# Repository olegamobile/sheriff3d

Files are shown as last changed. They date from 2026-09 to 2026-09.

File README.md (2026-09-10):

# ⛵ Jouët Sheriff 600 — Высокоточная 3D модель для печати

Параметрическая 3D-модель классической французской парусной яхты **Jouët Sheriff 600** (конструктор — **Philippe Harlé**, верфь — **Yachting France**, 1969–1976 гг.), созданная по оригинальным чертежам теоретического чертежа (Lines Plan) из журнала *Bateaux* (октябрь 1969 и июль 1973), официальной документации верфи и архивным фотографиям.

Модель полностью твердотельная (100% Watertight 2-manifold) и оптимизирована для FDM 3D-принтера **Flashforge Adventurer 3** (область печати 150 × 150 × 150 мм) в масштабе **1:45**, а также экспортирована в масштабе **1:1**.

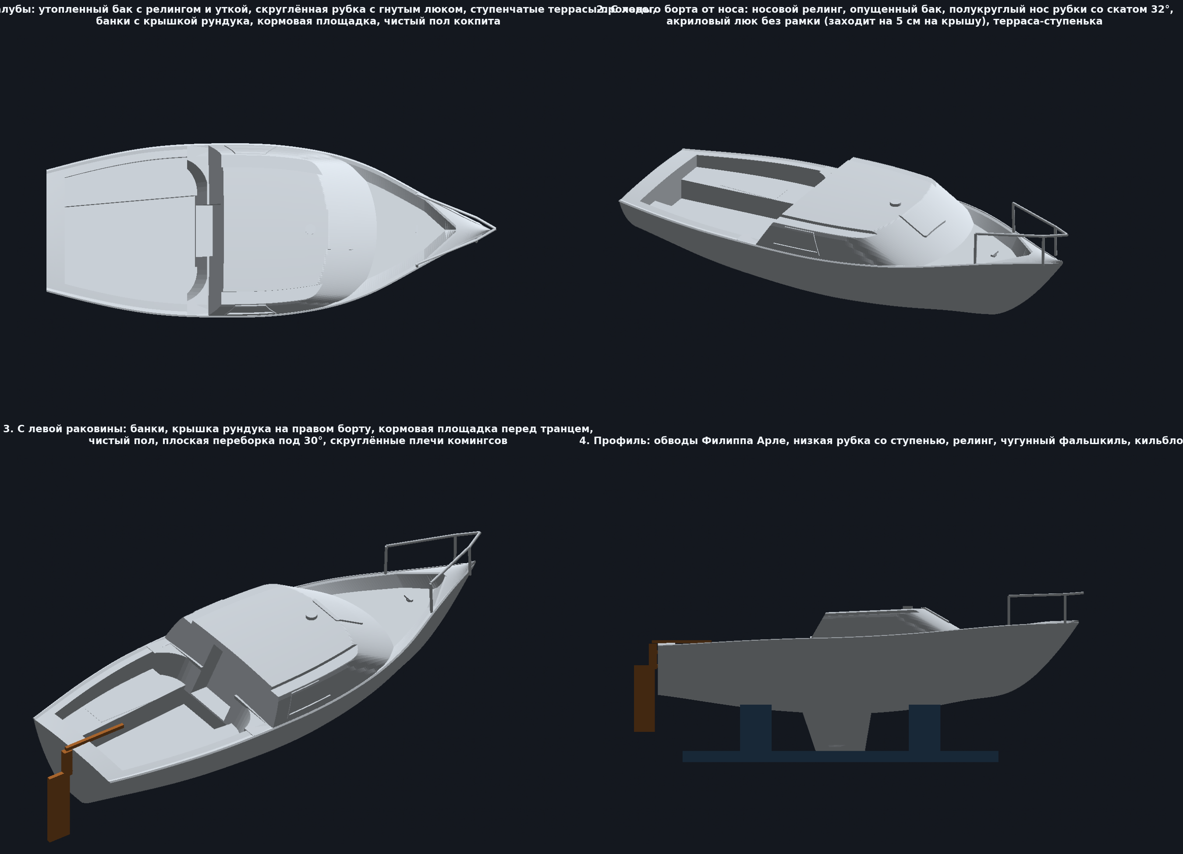
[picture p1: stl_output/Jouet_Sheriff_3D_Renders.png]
Jouet Sheriff 600 3D Renders


---

## 📐 Характеристики прототипа (Jouët Sheriff 600)

- **Длина наибольшая (LOA):** 6.00 м (6000 мм)
- **Длина по КВЛ (LWL):** 5.00 м (5000 мм)
- **Ширина наибольшая (Bmax):** 2.31 м (2310 мм)
- **Осадка (Draft):** 0.85 м (чугунный фальшкиль)
- **Высота надводного борта:** нос — 980 мм, мидель — 760 мм, транец — 650 мм
- **Водоизмещение:** ~850 кг (балласт 300 кг)
- **Материал оригинала:** Стеклопластик (GRP)

---

## 🧩 Особенности геометрии версии V4 (палуба по фотографиям реальной лодки)

Подводная часть, обводы, транец, фальшкиль и стыковочные пазы киля не менялись с V3. Палуба, рубка и кокпит построены заново по фотографиям из `real_photos/`:

1. **Утопленный бак.** Узкий планширь (50 мм) остаётся на уровне борта и чуть наклонён внутрь, дальше скос 150 мм вниз к опущенной палубе: у рубки она ниже на 70 мм, к носу — на 160 мм; к штевню углубление сходится клином. Посередине бака — маленькая **швартовая утка поперёк лодки**.
2. **Рубка во всю ширину:** боковые стенки — плоские, поднимаются прямо от кромки борта (привального бруса), повторяя его обводы, наклонены внутрь на 20°; крыша почти плоская, кормовые углы острые. Вдоль обоих краёв крыши от кормовой кромки до самого её конца (канавка выбегает на скат и заканчивается ровно на дуге перегиба) идут **проходы-канавки** (220 мм, глубина 20 мм); ободок снаружи от канавки **трапециевидный**: внешняя грань — продолжение стенки, плоский верх 30 мм, скос 45° в канавку. По одному **трапециевидному окну** на борт (700/410 × 250 мм) целиком на стенке: верх и низ параллельны линии края крыши (45 мм от неё), наклонные рёбра параллельны кормовой переборке; приподнятая алюминиевая рамка и утопленное тонированное стекло.
3. **Скруглённый нос рубки:** плоская крыша впереди заканчивается полуэллипсом (400 мм вперёд по ДП), и от этой дуги передняя грань падает вперёд под 32° — поэтому и перегиб на крыше, и линия подножия на баке являются дугами, а углы к боковым стенкам плавно сглажены. На скате вверху — **люк из тонированного акрила** (плоская пластина без рамки), его задний край на ~50 мм перегибается через кромку на крышу. Мачта стоит на крыше чуть позади перегиба.
4. **Кормовая переборка** — одна плоскость, наклонённая вперёд на 30° (параллельно заднему ребру окна), спускается на 50 мм ниже уровня банок до порожка (Z 450, банки Z 500) и поднимается до крыши. Ниже уровня борта по бортам от неё рубка выступает назад вдоль комингсов «крыльями» (R 450), которые заканчиваются **вогнутыми четвертями окружности** (центр дуги в кокпите), касательными к комингсу и к переборке: каждая банка упирается в полукруглую стенку. Верх крыльев — на уровне планширя, заподлицо с ним. **Выше уровня борта** переборка — одна плоскость во всю ширину с острыми углами. В переборке **большой вход в рубку** — проём 700 мм от порожка почти до крыши, выполненный карманом глубиной 200 мм.
5. **Открытый кокпит:** плоская полоса планширя по борту (150 мм), упирающаяся в крылья рубки, ниже — банки, между ними углублённый пол; банки и пол идут до самого транца (кормовой банки нет, рундука нет). Банки заканчиваются полукруглыми карманами у крыльев рубки.
6. **Доска-упор для ног, стойки и балка оттяжки гика** в полу кокпита: доска 55 мм шириной лежит плашмя вдоль почти всего пола на двух стойках у его концов, поперечная балка между банками проходит над ней. Сечения увеличены до ~1,3 мм в масштабе ради печатаемости.
7. **Транец, навесной руль и румпель:** транец сплошной, перо руля навешивается снаружи, румпель проходит над транцем.
8. **Все плоские поверхности — точные плоскости:** рубка и кокпит собраны булевыми операциями (`manifold3d`), а не деформацией сетки корпуса, поэтому скат, крыша, банки, пол и переборка не имеют волн и ступенек.

---

## 📂 Файлы в репозитории (`stl_output/`)

### Масштаб 1:45 (Для Flashforge Adventurer 3, 150×150×150 мм)

| Файл | Назначение | Размеры (X × Y × Z, мм) | Особенности печати |
| :--- | :--- | :--- | :--- |
| **`Jouet_Sheriff_Waterline_1to45.stl`** | Ватерлинейная модель (только надводная часть: борта, палуба, рубка, кокпит) | 133.3 × 52.3 × 26.8 | **Печать БЕЗ поддержек**. Ложится плоским дном по КВЛ прямо на стол. ~22 г PLA, ~3 часа. |
| **`Jouet_Sheriff_Split_Keel_1to45.stl`** | Нижняя половина (днище и фальшкиль с балластом) | 111.9 × 29.2 × 19.0 | **Печать БЕЗ поддержек**. Верх плоский (Z=0), класть срезом на стол. Внутри 2 паза под штифты. ~4.5 г PLA, ~45 мин. |
| **`Jouet_Sheriff_Split_Deck_1to45.stl`** | Верхняя половина (палуба, рубка, кокпит под склейку с килем) | 133.3 × 52.3 × 26.8 | **Печать БЕЗ поддержек**. Внизу 2 паза под штифты. ~22 г PLA, ~3 часа. |
| **`Jouet_Sheriff_Full_1to45.stl`** | Монолитная модель (корпус с килем целиком) | 133.3 × 52.3 × 45.8 | Требуются древовидные поддержки под скулы корпуса. |
| **`Jouet_Sheriff_Rudder_1to45.stl`** | Навесной руль с румпелем и петлями транца | 24.6 × 1.7 × 29.1 | Печатать плашмя. ~0.3 г PLA, ~15 мин. |
| **`Jouet_Sheriff_Display_Cradle_1to45.stl`** | Настольный кильблок-подставка под обводы днища | 100.0 × 48.9 × 18.3 | **Печать БЕЗ поддержек**. |
| **`Jouet_Sheriff_Rigging_1to45.stl`** | Рангоут (мачта 151 мм, гик, краспицы) | 61.0 × 21.1 × 151.1 | Печать по диагонали стола Adventurer 3 (диагональ 212 мм). |
| **`Jouet_Sheriff_Assembly_Preview.obj`** | 3D-сцена сборки (лодка + кильблок + руль) | — | Для открытия в 3D-просмотрщике или слайсере. |

### Полноразмерные модели (Масштаб 1:1, LOA = 6000 мм)
- **`Jouet_Sheriff_Full_1to1.stl`** (6000 × 2354 × 2060 мм)
- **`Jouet_Sheriff_Waterline_1to1.stl`** (6000 × 2354 × 1205 мм)

---

## 🎨 Интеграция с Blender (Blender MCP & `.blend`)

В репозиторий добавлен готовый проект для Blender:
- **`Jouet_Sheriff_600.blend`** — Сцена Blender 5.2 со структурированными коллекциями:
  - `Jouet_Sheriff_1to45` (разбитая на детали модель: палуба, киль, руль, рангоут, кильблок).
  - Настроенные PBR-материалы (гелькоут корпуса, тиковые банки, тонированный акрил, чугунный киль, алюминиевый рангоут).
  - Студийный свет (Key, Fill, Rim) и настроенная камера.
- **`build_blender_project.py`** — Автоматический скрипт сборки сцены в Blender.
- **Blender MCP:** настроен аддон `blender_mcp` и сервер для прямого взаимодействия AI-агентов с 3D-вьюпортом Blender.

---

## 🖨️ Рекомендации по печати на Flashforge Adventurer 3

1. **Слайсер:** FlashPrint (или Cura / OrcaSlicer с профилем Adventurer 3).
2. **Материал:** PLA (белый для палубы/корпуса, коричневый/серый для руля и кильблока).
3. **Высота слоя:** `0.18 мм` (стандарт) или `0.12 мм` (высокая детализация).
4. **Стенки (Shells):** 2 периметра (0.8 мм).
5. **Заполнение (Infill):** 15% (Gyroid или Hexagon).
6. **Сборка разборной модели (`Split_Deck` + `Split_Keel`):**
   - Обе детали имеют ответные отверстия диаметром ~2.4 мм на плоскости ватерлинии: в киле глубиной 4 мм, в палубе — 2.9 мм (над кормовым отверстием лежит пол кокпита).
   - Отрежьте два кусочка обычного прутка PLA 1.75 мм длиной по 6–6.5 мм.
   - Вставьте их в отверстия в качестве центровочных штифтов и соедините половинки на каплю цианакрилатного клея (суперклея).

---

## 🛠️ Структура скриптов и генерация

- **`generate_sheriff_models.py`** — Главный генератор всех STL и OBJ моделей.
  - Корпус: сплайны по 13 шпангоутам, непрерывные замкнутые шпангоутные кольца (Ring Topology) с плоской палубой.
  - Рубка, кокпит, окна, люк, утка, рундук и стойки — отдельные тела, объединённые/вырезанные через `manifold3d`. Все размеры палубы вынесены в блок параметров в начале файла.
- **`render_v3_clean.py`** — Рендер предпросмотра (4 ракурса): собственный ортографический z-buffer-растеризатор с диффузным освещением. Не используйте `Poly3DCollection` из mplot3d — он сортирует полигоны по центрам и на длинных треугольниках после CSG рисует ложные «рваные» полосы.
- **`real_photos/`** — Фотографии конкретной лодки, главный ориентир для палубы.
- **`chez_downloads/`** и **`extracted_pdf_assets/`** — Исходные материалы, PDF выпусков журнала *Bateaux* и извлеченные сканы чертежей.

### Установка и запуск:
```bash
python3 -m venv .venv
.venv/bin/pip install numpy scipy trimesh manifold3d matplotlib networkx rtree shapely pillow
.venv/bin/python generate_sheriff_models.py
.venv/bin/python render_v3_clean.py
```

---

## 📌 Инструкции для разработчиков и AI-агентов

Если вы дорабатываете проект с помощью AI-агента (Cursor, Claude, Copilot, Antigravity), обязательно ознакомьтесь с файлом [AGENTS.md](AGENTS.md) — там описана математическая модель, правила сохранения водонепроницаемости сетки и план модификации палубной части по индивидуальным замерам.

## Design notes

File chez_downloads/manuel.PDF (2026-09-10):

# Manuel de l'utilisateur

CARACTERISTIQUES PRINCIPALES

- Longueur maximum - avec balcon | 6 m 22
- Longueur maximum - sans balcon | 6 m 08
- Largeur au maître bau | 2 m 36
- Longueur flottaison | 4 m 70
- Hauteur totale (sans capote) | 2 m 06
- Tirant d'eau | 0 m 92
- Déplacement à vide (départ usine, sans suppléments) | 825 Kg
- Volume d'insubmersibilité (mousse polyuréthane) | 1 m3600
- Surface grand'voile | 10m260
- Surface foc n° 1 | 4m295
- Surface génois | 9m285
- Surface tourmentin | 2m250
- Surface spinnaker | 25 m2
- Jauge brute | 2 Tx 98
- Poid du lest | 225 Kg

## Shemas non commentés :

Plan de voilure

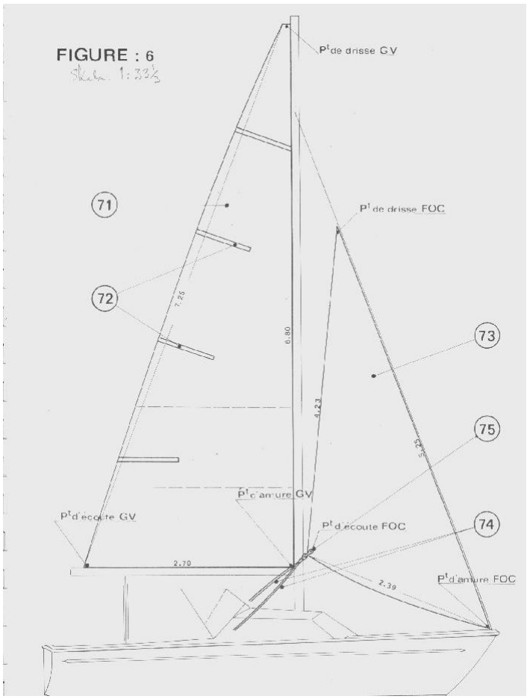
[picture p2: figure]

Détail voilure

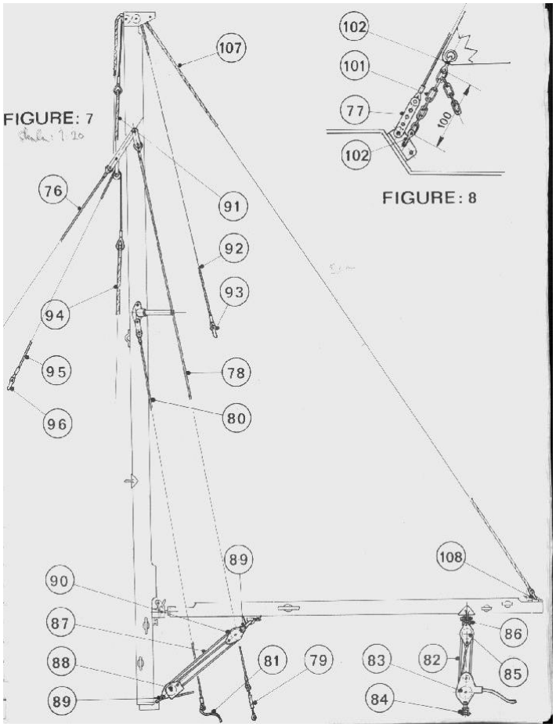
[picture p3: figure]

Pied de mât

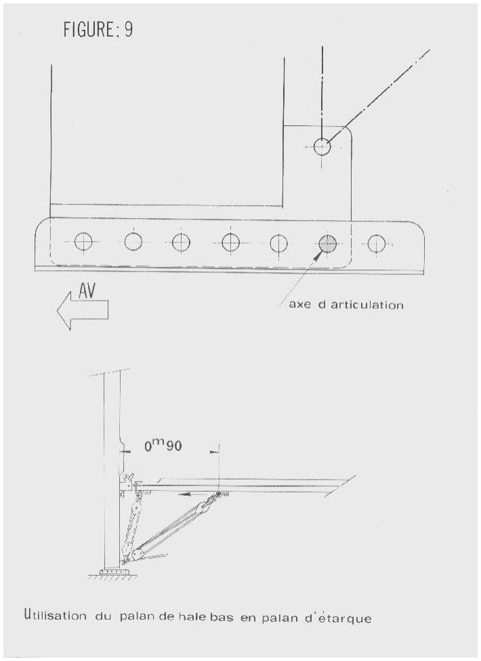
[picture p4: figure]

Béquillage

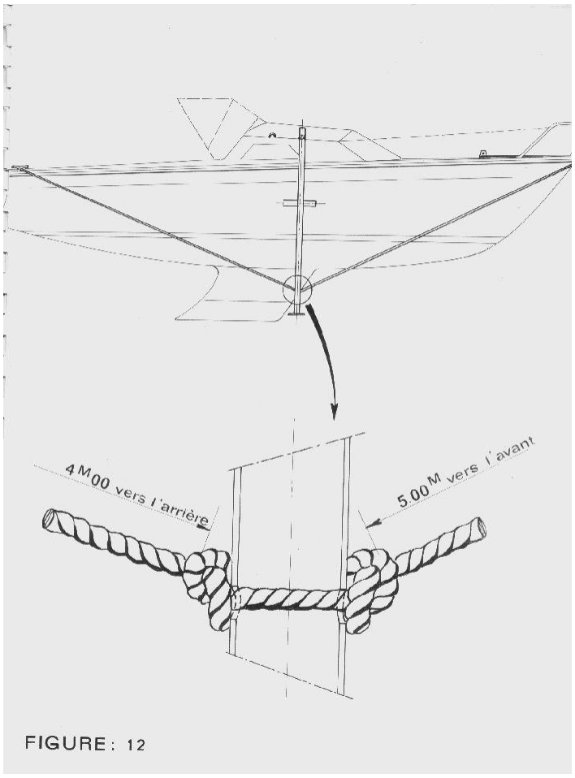
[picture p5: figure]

Capote

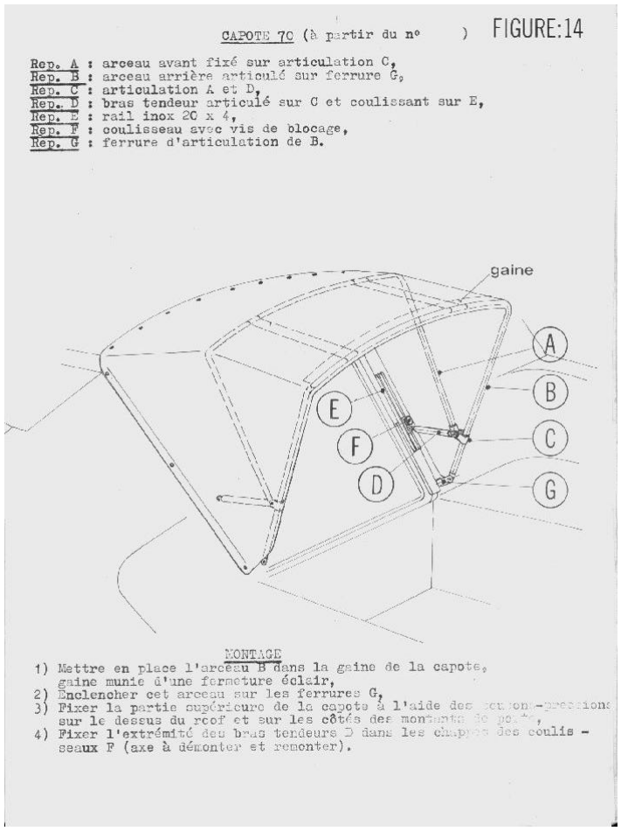
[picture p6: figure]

WC Marin

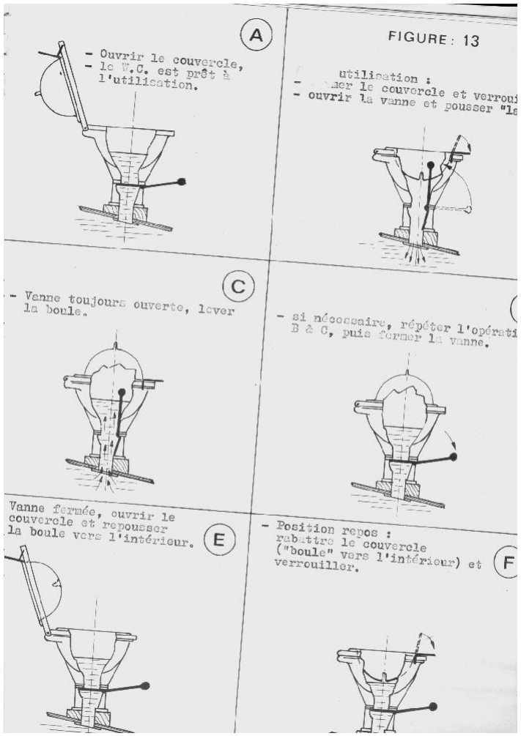
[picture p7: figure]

ACCASTILLAGE :

Pont (figure 1) :

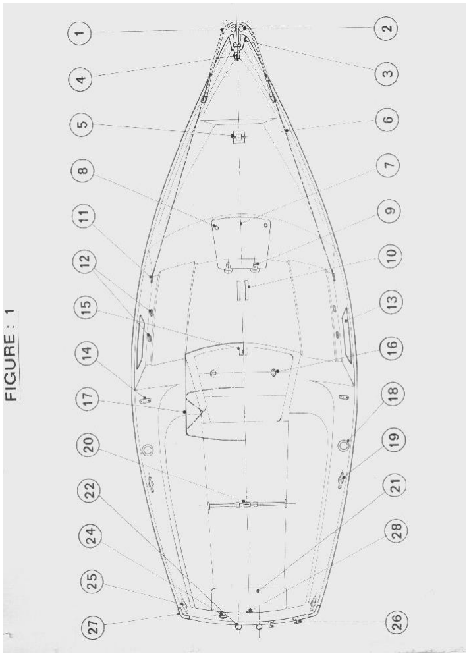
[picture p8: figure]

1 | 1 balcon avant en tube inox,
2 | 2 feux de route rouge et vert, (version luxe)
3 | 1 davier d'étrave,
4 | 1 ferrure d'étai,
5 | 1 bitte aérateur,
6 | 1 filière câble gaine plastique (version luxe)

7 | 1 panneau avant ouvrant en plexiglas,
8 | 2 poignées de fermeture du panneau,
9 | 2 charnières de panneau,
10 | 2 cornières de pied de mât,
11 | 2 ferrures d'accrochage de filière, (version luxe)
12 | 4 cadènes de haubans et bas-haubans,
13 | 2 hublots avec entourage alu,
14 | 2 filoirs plastique,
15 | 1 serrure de porte d'entrée de cabine, avec 2 clefs,
16 | 2 charnières de porte d'entrée de cabine,
17 | 1 capote rabattable,
18 | 2 winches nylon,
19 | 2 taquets nylon,
20 | 1 barre d'écoute avec coulisseau et butées,
21 | 1 banc arrière amovible,
22 | 2 balles de vidange,
24 | 1 ensemble douille et dame de nage,
25 | 2 taquets arrière nylon,
26 | 2 rails pour chaise moteur H.B. (GOIOT -Réf. 900)
27 | 2 embouts de défense arrière,
28 | 1 plaque de constructeur,

2 - AMENAGEMENT INTERIEUR

(figure 2) :

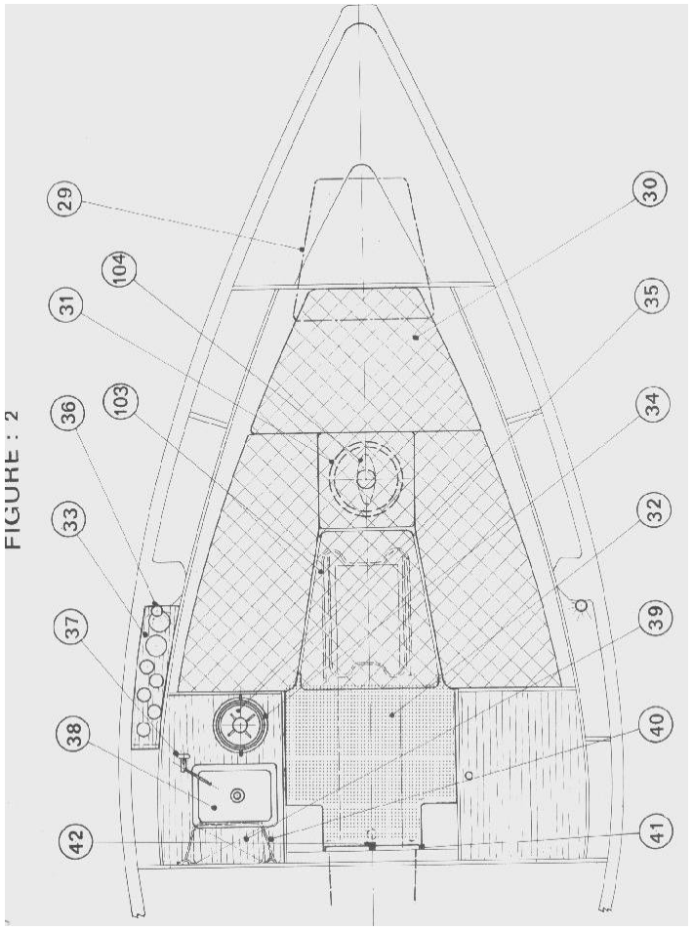
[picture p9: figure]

29 | 1 panneau amovible formant allonge de couchette rangement sous pontage,
103 | 1 jeu de pieds repliables pour utilisation du panneau en table repas (version luxe)
30 | 1 jeu de 5 coussins,

31 | 1 WC plastique, (version luxe)
32 | 1 moquette,
33 | 1 équipet à bouteilles et verres,
34 | 1 cardan à réchaud (version luxe)
35 | 1 bouteille 40 heures avec brûleur, (version luxe)
36 | 2 feux blancs d'intérieur, (version luxe)
37 | 1 pompe Whale à main, (version luxe)
38 | 1 évier plastique avec vidange, (version luxe)
39 | 1 jerrican de 10 litres, (version luxe)
40 | 1 sandow avec 2 crampons, (version luxe)
41 | 1 trappe de glacière,
42 | 1 fermeture de glacière,
104 | 1 pièce alu de profilage sortie WC (version luxe)

3 - GOUVERNAIL

(figure 3, 4 et 5) :

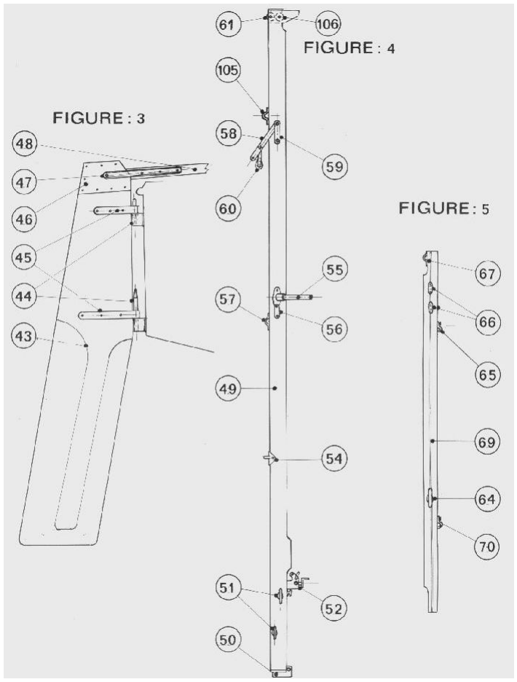
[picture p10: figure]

43 | 1 safran en acajou verni,
44 | 2 aiguillots sur tableau,
45 | 2 fémelots sur gouvernail,
46 | 2 plaques d'usure,
47 | 2 lattes d'articulation de

barre,
48 1 barre en frêne.

B - MATURE, VOILURE, GREEMENT :

1 - MAT (figure 4) :

49 | 1 profilé de mât métallique anodisé,
50 | 1 pied de mât, avec axe et écrou,
51 | 4 taquets de drisses,
52 | 1 articulation de bôme,
54 | 1 œil de tangon,
55 | 2 barres de flèche,
56 | 2 lattes de bas-haubans,

## Comment gréer votre " SHERIFF "

A - Dressage du mat :

S'assurer préalablement, à l'aide de votre liste (P. 4-5-6) que le gréement est complet. Tout doit être clair sur le mât ; Vérifier que toutes les pièces du mât, réas, ferrures, poulies, drisses, manilles, sont bien fixées. Mâter légèrement les écrous. Fixer les ridoirs, lattes et aiguillettes
(1) sur les galhaubans, étai, bas-haubans. Les détendre au maximum en s'assurant toutefois, pour les ridoirs, qu'il reste suffisamment de filets engagés dans la cage. L'étai doit être fixé provisoirement au dernier trou sur les lattes (77) figure 8. Fixer les bas-haubans (80) sur les cadènes avant du roof en utilisant les aiguillettes. Ramener tous les autres filins le long du mât et les y maintenir en les ceinturant avec un sandow, l'étai bien dégagé sur la face avant du mât. Dresser le mât sur son embase, le sabot de pied de mât venant entre les deux cornières fixées sur le roof, caler avec le pied. Une fois vertical, un seul homme suffit à le tenir en poussant vers l'avant pendant que l'on fixe d'étai. 1) Fixer l'étai avant sur le premier trou de la ferrure d'étrave (figure 8) ; 2) Fixer les deux ridoirs de galhaubans sur les cadènes arrière ; à ce moment, le mât tient seul ; 3) Le gréement étant détendu, fixer le sabot de pied de mât, passer l'axe dans le deuxième trou en partant de l'arrière sur les cornières (figure 9) ; 4) Fixer les aiguillettes des bas-haubans sur les cadènes avant du roof. (1) Aiguillettes : Bouts de nylon de faible diamètre qui, passés plusieurs fois dans l'œil des bas-haubans et dans la cadène correspondante, remplacent les ridoirs. L'avantage de ce système, en plus de l'économie de poids et de prix, est qu'on obtient quasi automatiquement la tension requise pour un bon réglage.

B- TENSION DES HAUBANS :

A L'arrêt, il ne faut pas que le mât penche sur bâbord ou tribord. S'assurer, avant matage, que les haubans bâbord et tribord ont la même longueur ; Ceci est valable pour les bas-haubans. Tendre d'abord l'étai avant (2ème ou 3ème trou). Tendre ensuite les galhaubans pour terminer pas les bas-haubans (aiguillettes) ; Les bas-haubans doivent être sensiblement moins tendus que les galhaubans. L'étai avant doit être le plus tendu. Un coup d'œil sur l'engoujure du mât vers le haut vous confirmera que le mât n'est pas infléchi sur bâbord ou sur tribord. Il doit avoir une légère quête sur l'arrière. Si le mât est bien en place au repos, encore faut-il qu'il en soit de même quand les voiles sont enverguées. Il y aura lieu de parfaire le réglage sous voiles en mer. Après quelques sorties en mer, surtout par brise fraîche, il faudra reprendre le jeu dû à l'allongement des câbles neufs.

III - REGLAGES

1 - LE FOC : Les filoirs d'écoute ont une position fixe. Par conséquent, pour avoir un point de tir correct, il faut régler le point d'armure sur le foc. En principe, 100 mm de chaîne sont utilisés pour la fixation du point d'armure ; Mais si le foc faseye dans le haut, il faut rehausser cette distance et repérer le maillon utilisé. Procéder de même pour le génois.

2 - LA GRAND'VOILE : Il n'y a aucun réglage à faire, sinon d'essayer de lui donner plus ou moins de creux suivant la force du vent et l'allure. Par vent faible et aux allures portantes, ne pas trop tendre la ralingue sur la bôme et ne pas trop étarquer. Par vent fort et au plus près, tendre fortement la ralingue sur la bôme et étarquer à bloc en tirant la bôme vers le bas.

3- LA PRISE DE RIS (figure 10 & 11) : 1- Se mettre en panne (le foc bordé à contre - la barre à fond sous le vent). 2- Choquer la drisse de grand'voile, 3- Passer la bosse dans l'œil arrière de la bande de ris si elle n'est pas déjà en place, suivant figure 10.

4- Crocher l'œil extrême avant de la bande de ris dans le croc de la ferrure de bôme.

5- Étarquer la voile sur la bôme à l'aide de la bosse de ris. Une fois raidie à fond, tourner la bosse sur le taquet de la bôme.

6- Hisser la voile et étarquer la drisse.

7- Nouer les garcettes. Même principe pour la deuxième bande de ris - en utilisant le réa situé en avant du premier ris.

NOTA Cette méthode permet également de prendre des ris, le bateau étant en route -(du vent de travers au vent arrière, la voile peut être difficile à amener étant plaquée contre les haubans par le vent). Dans ce cas, border la grande écoute un peut plus que la normale pour dégager la voile.

IV UTILISATION DES ACCESSOIRES GREEMENT DE SPI

(figure 15) :

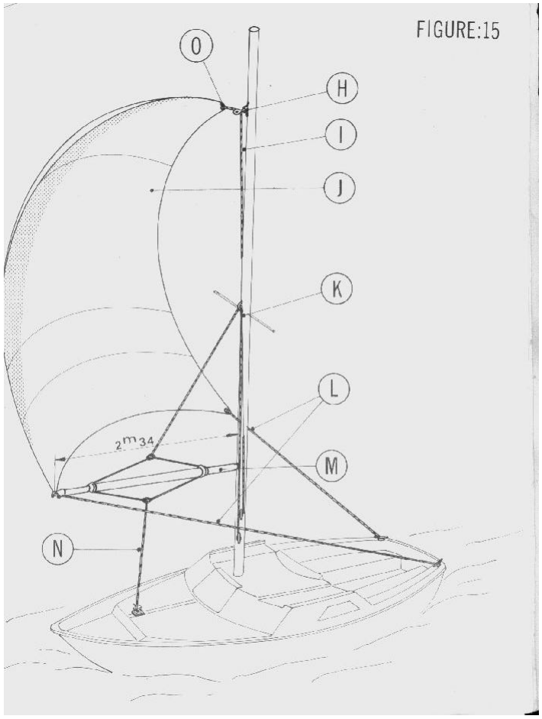
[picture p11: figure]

Rep. O | 1 mousqueton
Rep. I | 1 drisse longueur 12 m 50 - Diamètre 8 polypropylène
Rep. | 1 poulie à axe amovible

H
Rep K | 1 hale-haut polypropylène - Diamètre 8 -Longueur 5 m 50
Rep J | 1 spinnaker,
Rep L | 2 bras ou écoute de spi tergal tressé diamètre 8, longueur 8 m 20 chaque
Rep M | Tangon télescopique (longueur maxi. Jauge 2 m 34)
Rep N | 1 hale-bas polypropylène diamètre 8 -longueur 3 m 00

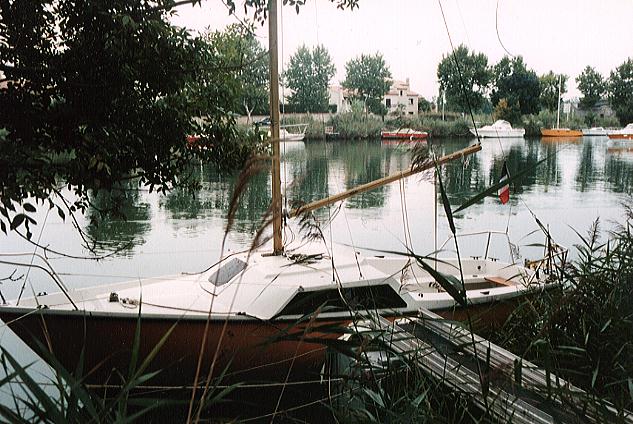
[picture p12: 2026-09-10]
downloaded_assets/assets/photos/horn.jpg

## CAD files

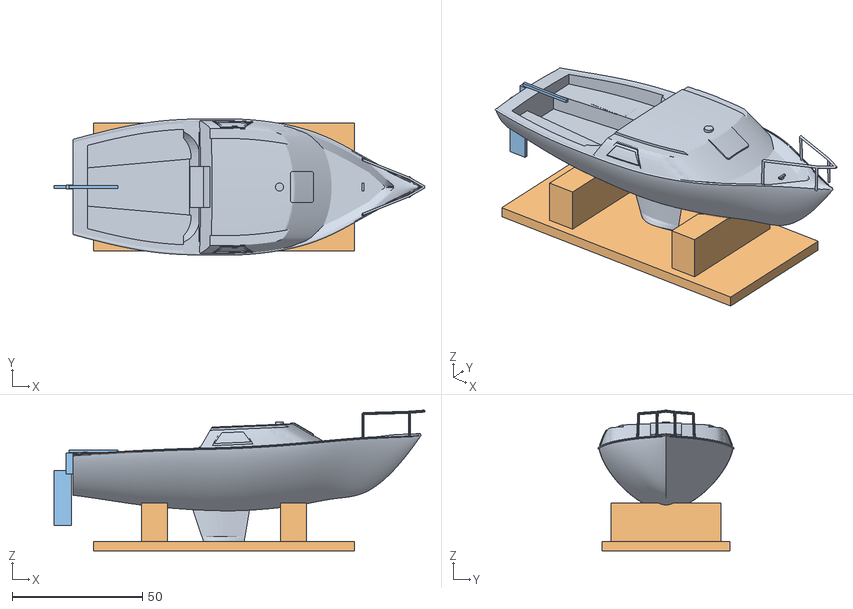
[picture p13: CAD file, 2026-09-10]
stl_output/Jouet_Sheriff_Assembly_Preview.obj
142.2 x 52.3 x 54.0
geometry_0
geometry_1
geometry_2

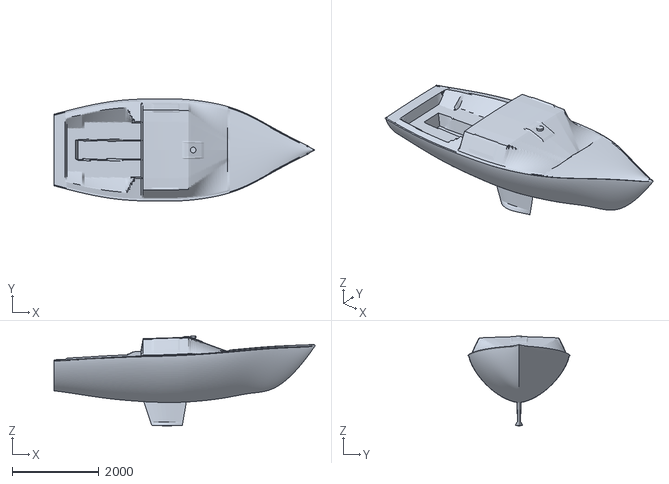
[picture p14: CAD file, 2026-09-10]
test_full_v3.stl
6000.0 x 2354.0 x 2060.8

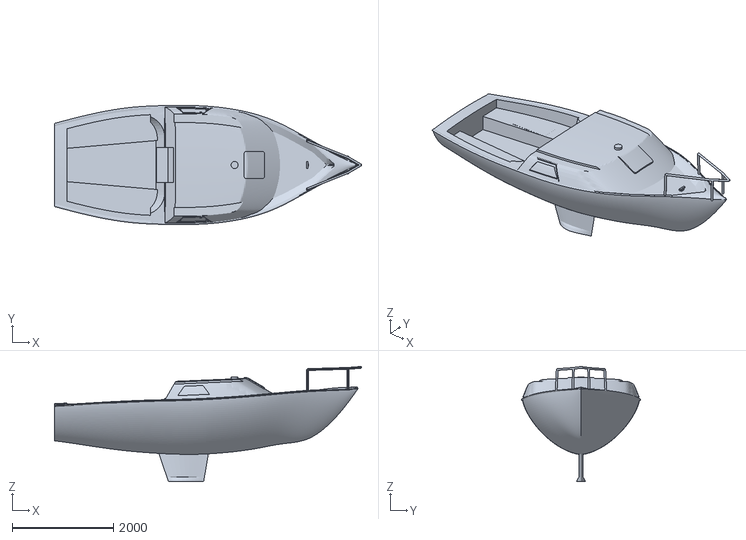
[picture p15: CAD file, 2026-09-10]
stl_output/Jouet_Sheriff_Full_1to1.stl
6069.0 x 2354.0 x 2274.5

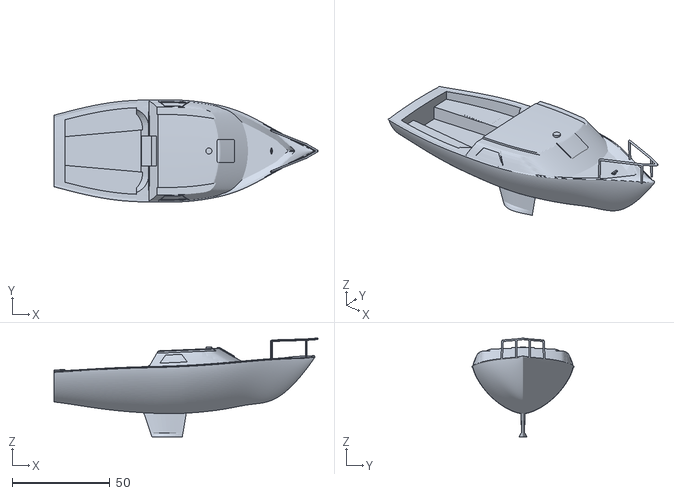
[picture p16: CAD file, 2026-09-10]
stl_output/Jouet_Sheriff_Full_1to45.stl
134.9 x 52.3 x 50.5

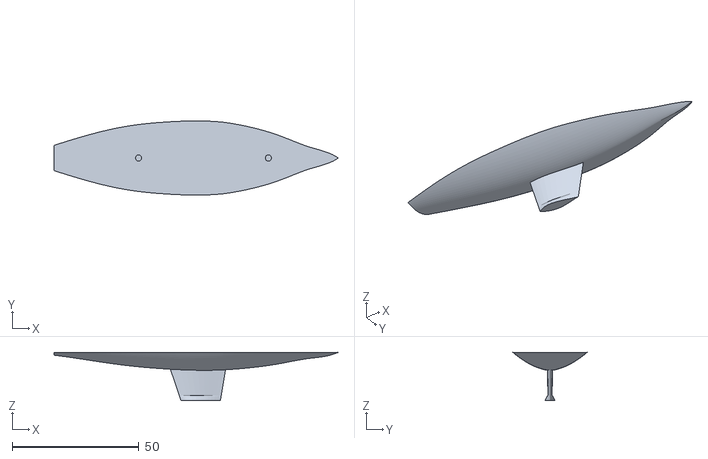
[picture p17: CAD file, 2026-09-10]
stl_output/Jouet_Sheriff_Split_Keel_1to45.stl
111.9 x 29.2 x 19.0

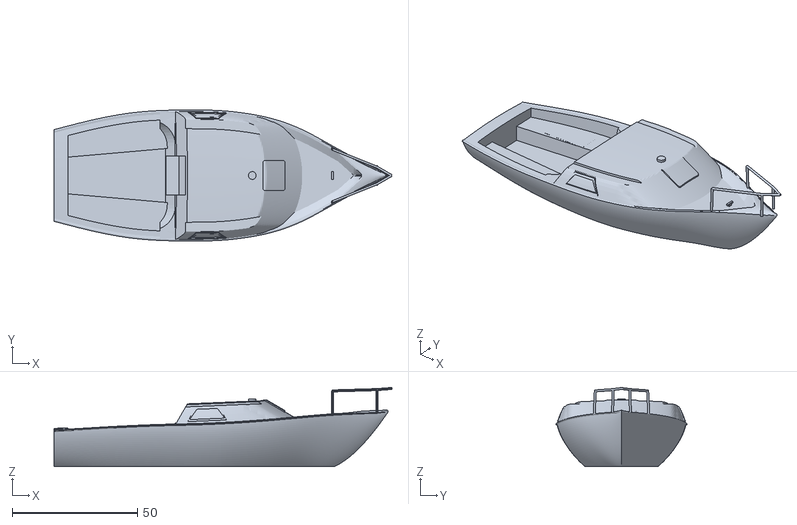
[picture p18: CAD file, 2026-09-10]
stl_output/Jouet_Sheriff_Split_Deck_1to45.stl
134.9 x 52.3 x 31.5

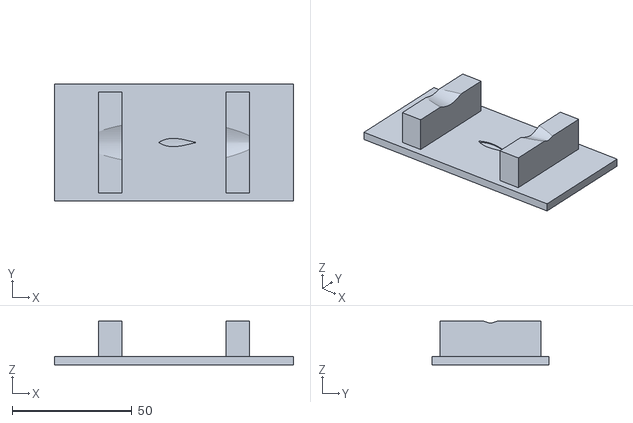
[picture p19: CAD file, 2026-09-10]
stl_output/Jouet_Sheriff_Display_Cradle_1to45.stl
100.0 x 48.9 x 18.3

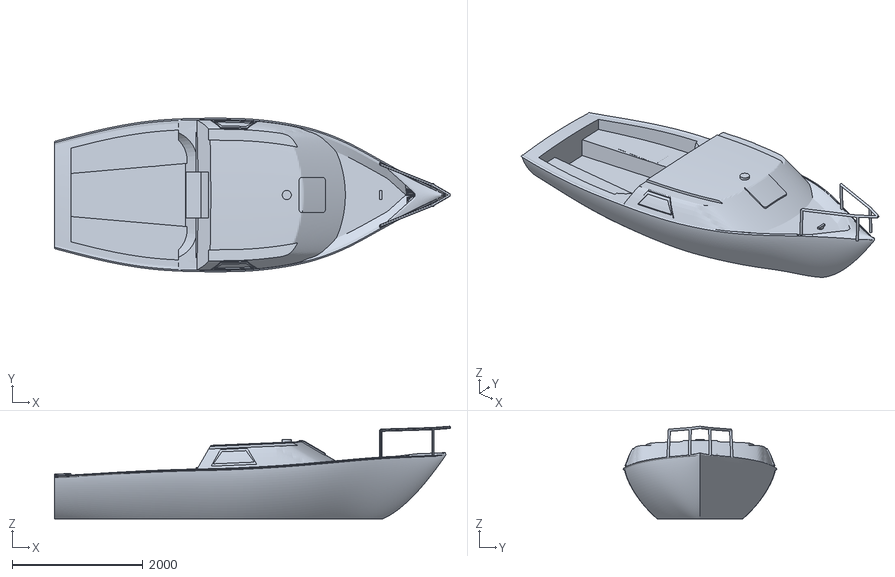
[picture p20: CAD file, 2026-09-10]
stl_output/Jouet_Sheriff_Waterline_1to1.stl
6069.0 x 2354.0 x 1419.5

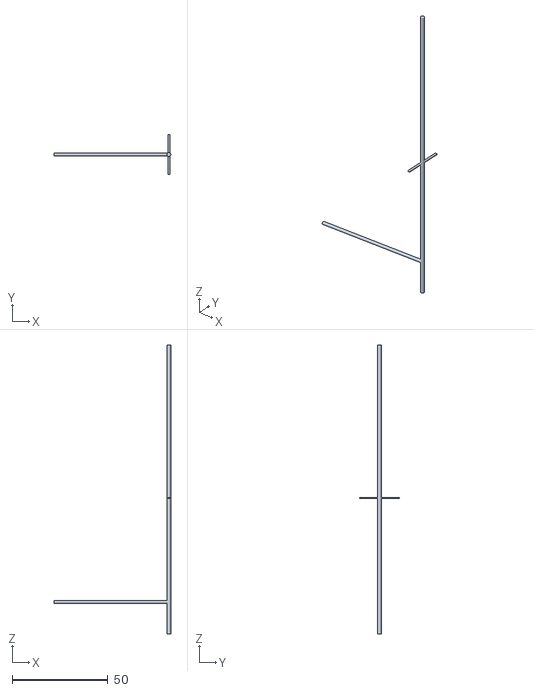
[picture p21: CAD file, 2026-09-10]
stl_output/Jouet_Sheriff_Rigging_1to45.stl
61.0 x 21.1 x 151.1

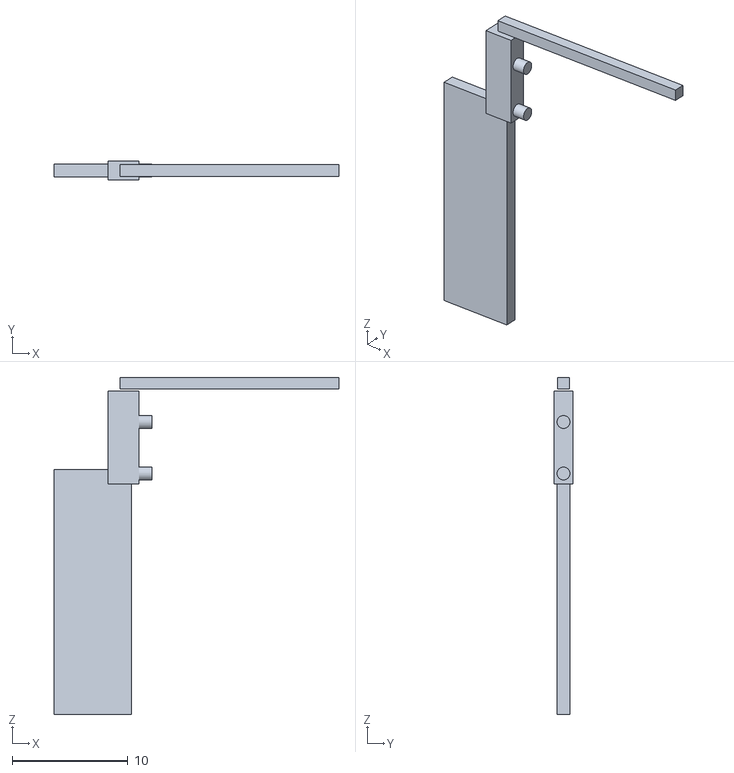
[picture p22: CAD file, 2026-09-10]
stl_output/Jouet_Sheriff_Rudder_1to45.stl
24.6 x 1.67 x 29.1

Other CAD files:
stl_output/Jouet_Sheriff_Waterline_1to45.stl
Jouet_Sheriff_600.blend

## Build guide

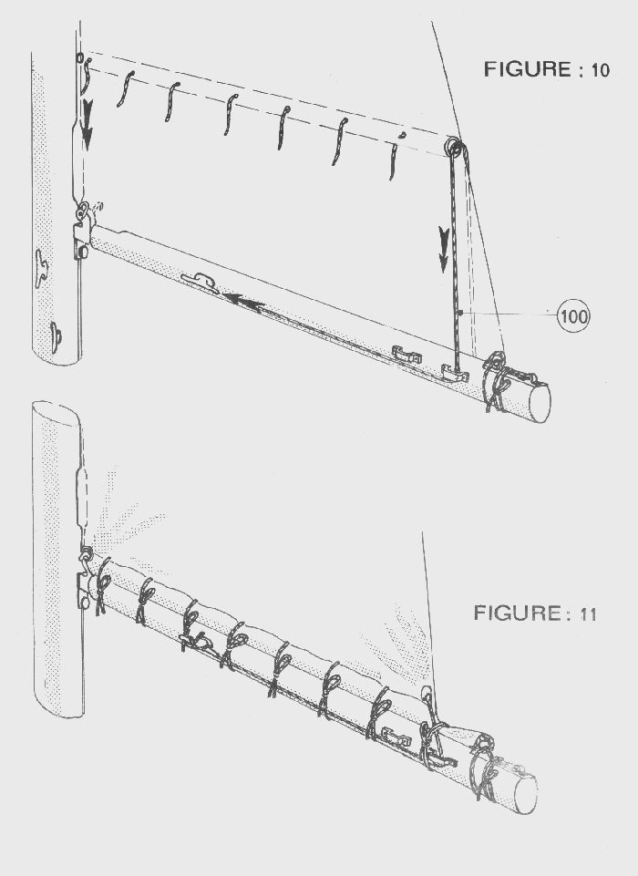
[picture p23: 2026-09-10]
downloaded_assets/assets/manual/ris.jpg

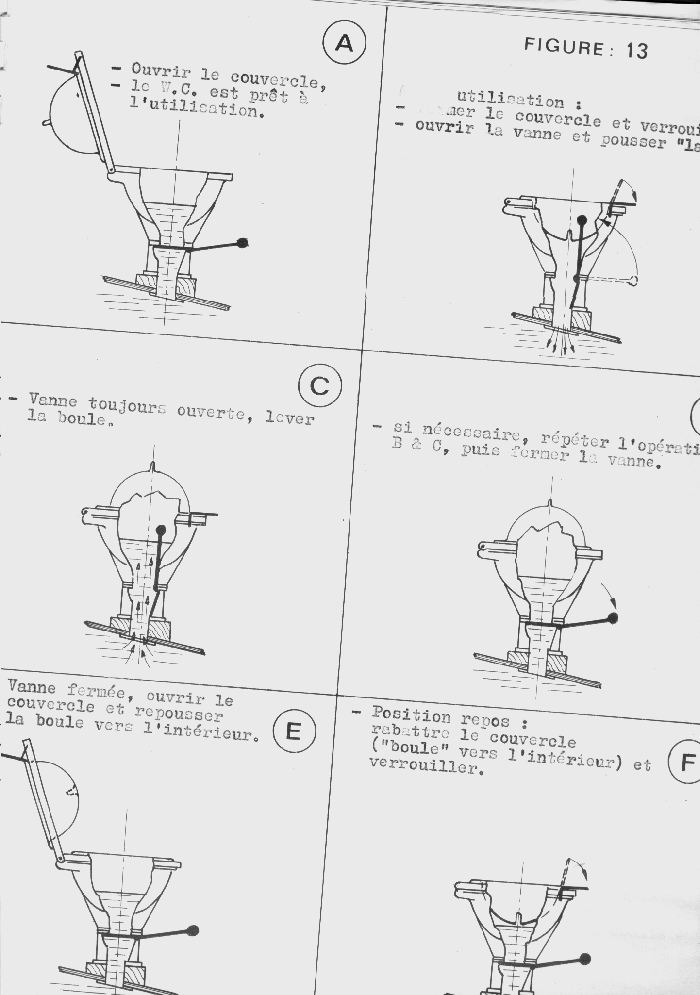
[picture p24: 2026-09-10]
downloaded_assets/assets/manual/wc.jpg

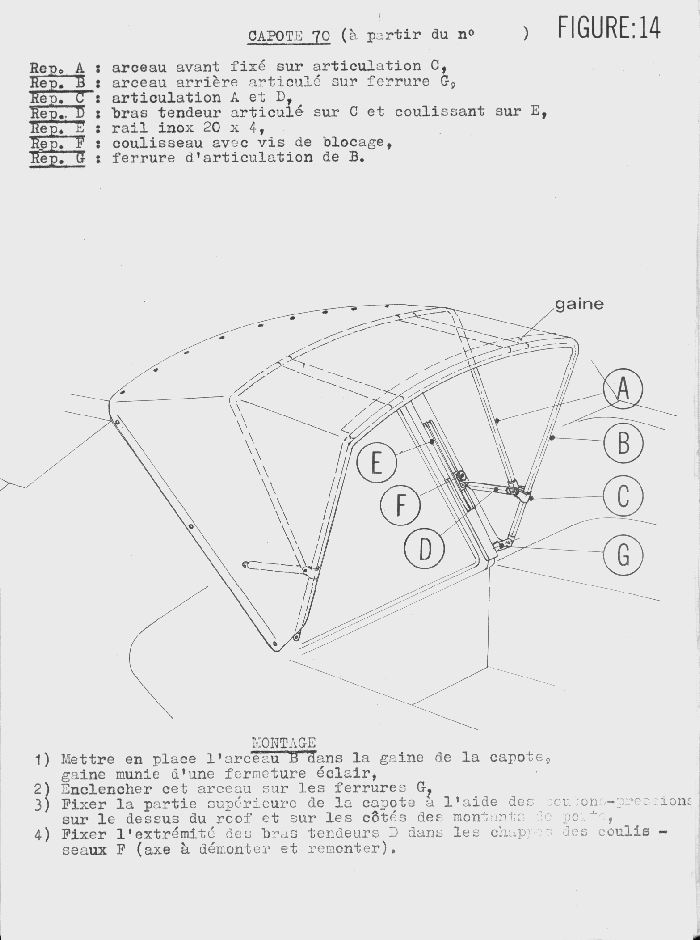
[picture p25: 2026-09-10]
downloaded_assets/assets/manual/capote.jpg

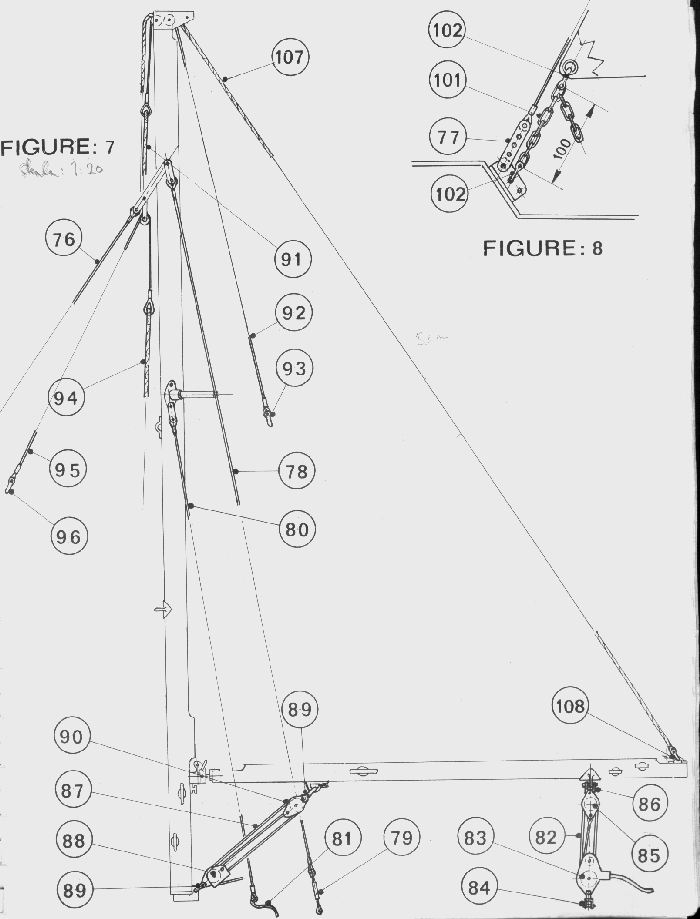
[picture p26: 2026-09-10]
downloaded_assets/assets/manual/vdetail.jpg

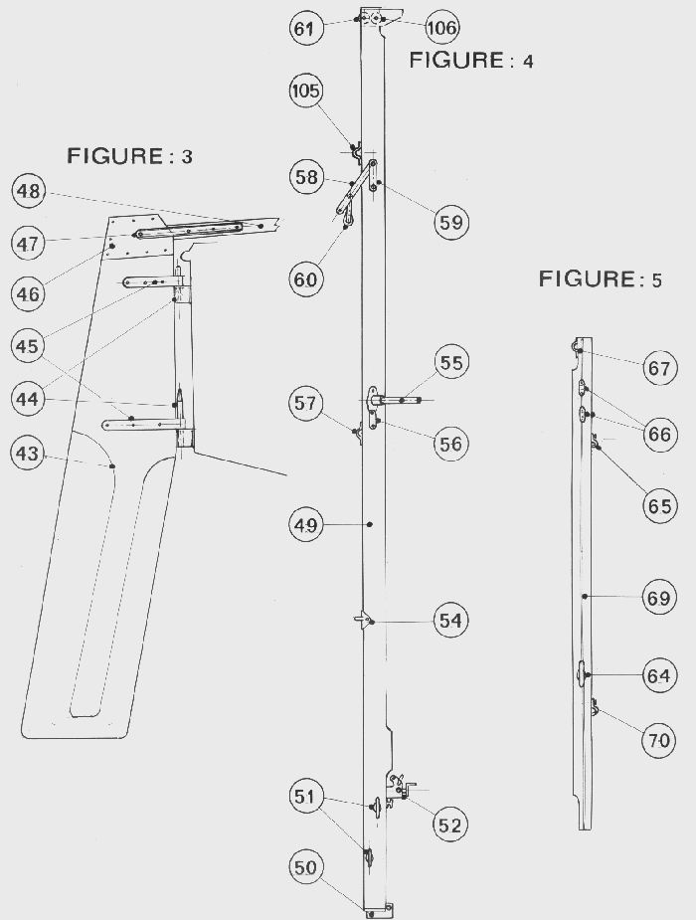
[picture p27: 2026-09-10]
downloaded_assets/assets/manual/gouv.jpg

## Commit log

2026-09-10 Rebuild deck, coachroof and cockpit from real boat photos (V4)
    Hull below the sheer, keel and keel pin sockets are unchanged (Split_Keel
    matches V3 exactly). Superstructure is now built from planar CSG bodies
    via manifold3d instead of deforming the hull rings:
    - long flat foredeck with a mooring cleat
    - full-beam coachroof, 20° tumblehome walls, 25° planar forward slope
    with a frameless tinted acrylic hatch, mast pad at the roof front edge
    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
    [Jouet_Sheriff_Assembly_Preview.obj, Jouet_Sheriff_Full_1to1.stl, Jouet_Sheriff_Full_1to45.stl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]
2026-09-10 Deck V4.1: rounded cabin nose, bench shoulders, toe rails, no locker/aft seat
    Per the owner's review of the photos:
    - locker box removed; benches and footwell now run to the transom
    - benches end at the bulkhead in quarter-round shoulders at deck height
    - coachroof nose rounded in plan (quarter-ellipse crease), aft roof
    corners rounded; side windows enlarged to ~75% of the wall height
    - low toe rails along the foredeck edges grow out of the cabin walls
    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
    [Jouet_Sheriff_Assembly_Preview.obj, Jouet_Sheriff_Full_1to1.stl, Jouet_Sheriff_Full_1to45.stl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]
2026-09-10 Deck V4.2: sunken foredeck, fully curved cabin front, roof walkways, flat foot-brace
    Per the owner's second photo review:
    - foredeck is sunk 120 mm inside a 150 mm gunwale strip with a sloped
    inner edge, closing in a V towards the stem; toe rails removed
    - the whole cabin front (wall foot and roof crease) now follows a
    quarter-ellipse in plan, giving one curved 25 deg sloping face that
    lands on the sunken foredeck; side-deck strip widened to 120 mm
    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
    [Jouet_Sheriff_Assembly_Preview.obj, Jouet_Sheriff_Full_1to1.stl, Jouet_Sheriff_Full_1to45.stl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]
2026-09-10 Deck V4.3: rounded roof nose with arc crease, variable-depth foredeck, mast at crease
    Per the owner's comparison of photo vs render:
    - the flat roof now ends in a half-ellipse (400 mm) and the 32 deg front
    face falls forward from that arc, so both the roof crease and the foot
    line on the deck are arcs; slope/wall corners blended (smooth min)
    - sunken foredeck is shallow at the cabin (70 mm) and deeper at the bow
    (160 mm), rim slope widened to 150 mm; planar sunken deck
    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
    [Jouet_Sheriff_Assembly_Preview.obj, Jouet_Sheriff_Display_Cradle_1to45.stl, Jouet_Sheriff_Full_1to1.stl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]
2026-09-10 Deck V4.4: 30° raked bulkhead with large companionway, roof walkway lips, narrow foredeck rim
    Per the owner's photo review:
    - aft bulkhead raked 30 deg (parallel to the window's slanted edges) all
    the way down to the seats; cockpit well clipped by the raked plane,
    footwell ends where the plane reaches seat level (bridge-deck sill)
    - large companionway opening (700 mm, seat level to just under the roof)
    as a 200 mm deep pocket cut from the whole assembly
    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
    [Jouet_Sheriff_Assembly_Preview.obj, Jouet_Sheriff_Display_Cradle_1to45.stl, Jouet_Sheriff_Full_1to1.stl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]
2026-09-10 Deck V4.5: flat raked bulkhead with sharp corners, walkway grooves instead of lips
    - aft roof corner rounding removed: the aft bulkhead is one flat 30 deg
    plane, as on the real boat
    - roof walkways are now plain grooves (220 x 20 mm) from the aft edge to
    the start of the nose, with a 60 mm roof rim outboard; the added rails
    that showed as loose slabs are gone
    - grooves are cut after the windows so the wrapped bezel sits on the rim only
    Hull and Split_Keel geometry unchanged (max surface deviation 0.00000 mm).
    Claude-Session: https://claude.ai/code/session_01JjzRQBqFLRKUBTcFTepxyz
    [Jouet_Sheriff_Assembly_Preview.obj, Jouet_Sheriff_Full_1to1.stl, Jouet_Sheriff_Full_1to45.stl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]
2026-09-10 Deck V4.6: grooves run to the roof crease, hatch wraps the crease, side windows back on the wall
    - walkway grooves lofted through the nose so they end exactly on the
    crease arc (the slope drops below the groove floor there)
    - forward hatch moved 100 mm aft: its aft edge wraps ~50 mm over the roof
    - side windows back to 250 mm high, fully on the wall (no roof wrap)
    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
    [Jouet_Sheriff_Assembly_Preview.obj, Jouet_Sheriff_Full_1to1.stl, Jouet_Sheriff_Full_1to45.stl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]
2026-09-10 Deck V4.7: rounded aft corners flush with the cabin wall, bulkhead down to a sill
    Per the owner's sketch:
    - the deck-level bench "shoulders" are gone; the cabin's aft end is now a
    Z-loft: flat raked bulkhead with plan-view corner radius shrinking from
    450 mm at seat level to zero at the roof, so the rounded end of each
    bench is one surface with the cabin side wall (roof corners stay sharp)
    - cabin wall foot drops vertically below the deck in line with the cockpit
    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
    [Jouet_Sheriff_Assembly_Preview.obj, Jouet_Sheriff_Full_1to1.stl, Jouet_Sheriff_Full_1to45.stl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]
2026-09-10 Deck V4.8: bench ends are concave semicircular pockets, bulkhead 50 mm below the seats
    - aft corner arcs flipped: the cabin now has wings running aft along the
    coamings that end in concave quarter circles (centre in the cockpit),
    tangent to the coaming and to the bulkhead; radius 450 at seat level,
    zero at the roof, so the pocket wall blends into the flat cabin wall
    - sill raised to 50 mm below the seats (SILL_Z 450), pocket floor 465
    - cabin assembled as aft_block ^ cabin_body over the whole length
    Claude-Session: https://claude.ai/code/session_01JjzRQB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
    [Jouet_Sheriff_Assembly_Preview.obj, Jouet_Sheriff_Full_1to1.stl, Jouet_Sheriff_Full_1to45.stl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]
2026-09-10 Deck V4.9: cabin walls down to the sheer, pocket arc tangent to the hull line, trapezoid roof rim
    - side-deck strip along the cabin removed (CABIN_MARGIN 0): the flat side
    walls rise straight from the rubbing strake following the hull outline
    - aft_block sides follow the hull and converge onto the wall-foot line at
    the wing tip, so the concave pocket arc starts tangent to the hull line
    at deck level and no longer clips the wall's lower aft corner
    - walkway groove cross-section is now a pentagon: the outer rim is a
    trapezoid (30 mm flat top, 45 deg slope into the groove)
    Hull and Split_Keel geometry unchanged (max surface deviation 0.00000 mm).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
    [Jouet_Sheriff_Assembly_Preview.obj, Jouet_Sheriff_Full_1to1.stl, Jouet_Sheriff_Full_1to45.stl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]
2026-09-10 Deck V4.10: side window edges parallel to the roof edge line
    The window trapezoid's top and bottom now follow roof_side_z(x) (45 mm
    below the roof edge) instead of being horizontal, so the window sits
    parallel to the roof as on the real boat.
    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
    [Jouet_Sheriff_Assembly_Preview.obj, Jouet_Sheriff_Full_1to1.stl, Jouet_Sheriff_Full_1to45.stl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]
2026-09-10 feat: add Blender 5.2 project, setup script, and Blender MCP integration
    [Jouet_Sheriff_600.blend]
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2026-09-10 Deck V4.11: pockets only below the sheer, flat bulkhead above; cabin clipped to the hull envelope
    - bench pockets (concave R450 wings) now exist only from the seats up to
    the gunwale level; their top is flush with the gunwale strip and above
    the sheer the raked bulkhead is one flat full-width plane
    - new hull_envelope (hull sides continued straight up from the sheer); the
    cabin body is intersected with it so its below-deck part no longer
    sticks out of the tucked-in topsides as a vertical skirt
    Claude-Session: https://claude.ai/code/session_01JjzRQBqFLR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
    [Jouet_Sheriff_Assembly_Preview.obj, Jouet_Sheriff_Full_1to1.stl, Jouet_Sheriff_Full_1to45.stl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]
2026-09-10 feat: add 1-click open_blender.bat launcher with auto-start MCP server
    [Jouet_Sheriff_600.blend]
2026-09-10 V5: rounded coachroof nose, curved acrylic hatch, stepped walkways, bow pulpit, clean cockpit sole and mast on roof
    [Jouet_Sheriff_600.blend, Jouet_Sheriff_Assembly_Preview.obj, Jouet_Sheriff_Display_Cradle_1to45.stl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]
